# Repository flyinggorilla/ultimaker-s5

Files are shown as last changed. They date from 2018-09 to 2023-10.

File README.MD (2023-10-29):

# Ultimaker S3/S5/S5/S7/ProBundle Material Profiles

## favorite materials
* FormFutura ApolloX (all colors)
* FormFutura BVOH

## additional great materials
* FormFutura PythonFlex
* FormFutura CrystalFlex
* FormFutura HDglass PETG
* Luvocom PAHT 9933BK 

## materials i stopped using
* FormFutura Helios PVA (I switched all soluble support to BVOH, which is much more reliable and no clogging any more.)

## __FormFutura ApolloX ASA__ for outdoor parts
There is a FormFutura ApolloX listed on the marketplace, but that one is STILL not  supporting material station properly, because it misses color and additional material profile settings. So choose this one and you should be fine.

ApolloX prints as easy as PLA, but is much more robust and perfectly suited for practical parts and outdoor use as it is water resistant, UV resistant and doesnt bend under the heat of the sun. The really only tradeoff is weaker interlayer adhesion.

* ASA Materials are updated and tested with Ultimaker S3/S5 Firmware 8.2.x+ and Cura 5.5.x+
* The marketplace delivered ApolloX profiles are still as of v2.0.0 only providing the bare minimum, and have not been tuned for colors, material station, robustness, dimensional stability and more.
These profiles here are tuned for practical-use parts, with higher temperature for higher layer adhesion, and dimensional correctness also for larger prints. It is still super easy to print with Dimafix (or similar) in place.

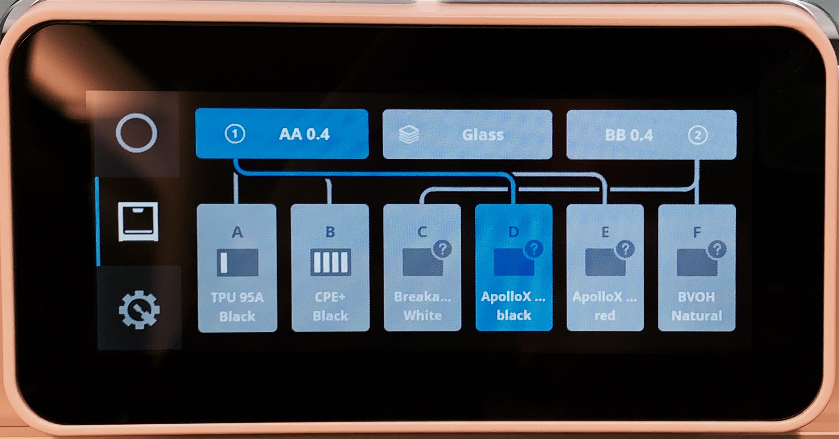
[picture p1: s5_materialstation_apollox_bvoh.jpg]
Formfutura ApolloX ASA and BVOH water soluble material


## __FormFutura BVOH__ water soluble support material
Forget PVA, BVOH is so much better more than justifying the higher price. Prints easier, didnt clog so far my BB 0.4, dissolves much quicker than PVA in warm water. Can be combined with many filaments, including ASA - my favorite material. Had so much of clogging issues with original Ultimaker PVA that i stopped using PVA entirely. Had then issues with FormFutura Helios PVA too.

## __Luvocom PAHT 9933BK__ for robust parts, but NOT outdoors. 
The biggest benefits of this Nylon material is much stronger inter-layer adhesion than ApolloX. Also it does not warp compared to other nylons. Prints well on Dimafix. Also it is fairly heat resistant.

This material is also available on the marketplace, but not optimized enough. Especially printing with 0.8mm Nozzle for larger parts caused lots of stringing. The profile lowered print temperature and increased retraction to reduce stringing. Drying the material upfront (12h 70°, or 4h 100°) is mandatory.

I learned the hard way, that this material strongly deforms in outdoor use, rendering it unusable.
ApolloX is still my favorite outdoor use material. However, I plan to test Durabio next, which is a PC/PMMA material that is UV resistant.

# Formfutura cardboard spool adapter for Ultimaker S5 and S3
FormFutura switched from plastic to cardboard spools recently. Great for environment, but problematic with Ultimaker spool holder, as the spools get stuck. This cardboard spool adapter for Ultimaker S3 and S5 will make it work again and uses little plastic. Printing two of these adapters solves the problem.

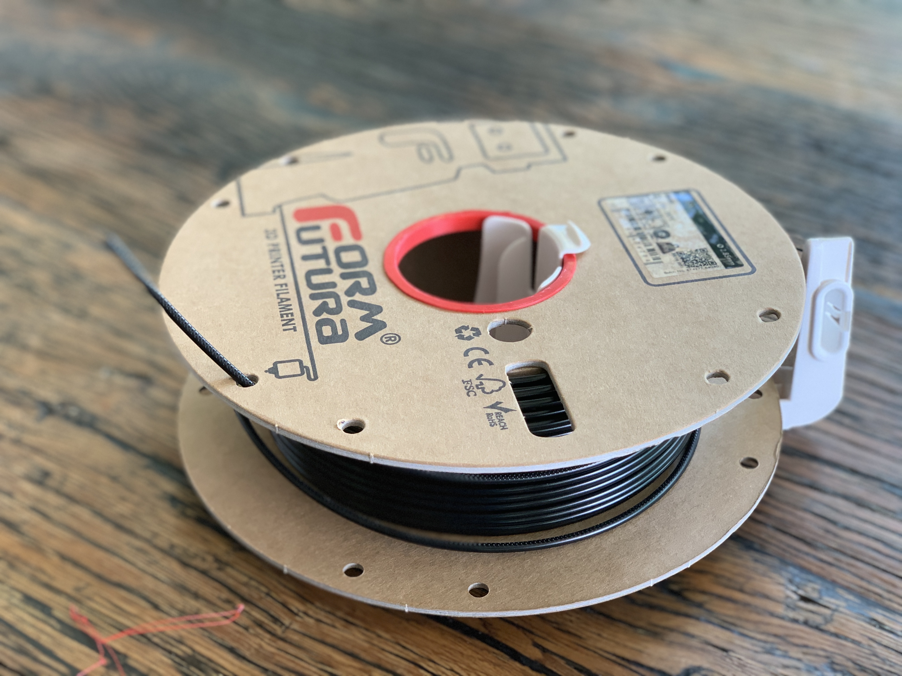
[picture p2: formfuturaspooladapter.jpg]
FormFutura cardboard spool adapter


https://grabcad.com/library/formfutura-cardboard-spool-adapter-for-ultimaker-s3-and-s5-1

# Python tool to manage material profiles on Ultimaker S3/S5/S5/S7/ProBundle printers
This tool allows to manage material profiles on Ultimaker S3/S5/S5/S7/ProBundle printers. It can be used to import, export, delete and list material profiles. 

## Material-Station
as of Cura 4.5 and S5 Firmware 5.5.12.20200226 there is no color information displayed with materials. this is ok for NFC based ultimaker material with color auto-detection, but not when manually assigning a 3rd party material to a material station bay.
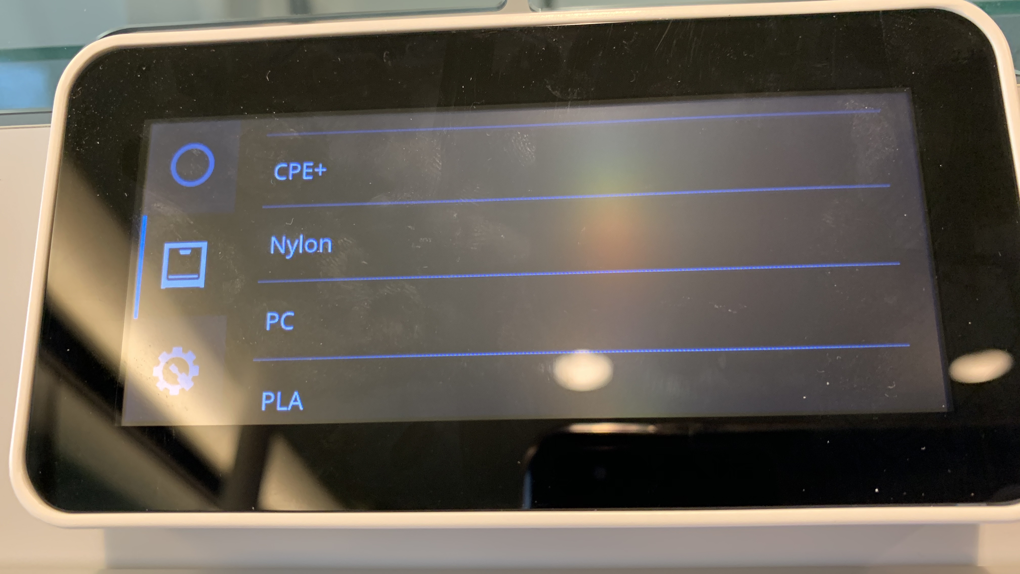
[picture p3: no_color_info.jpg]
no color information


The workaround for now is to turn every color variant into a unique material. This is what i did here for e.g. with ApolloX material.
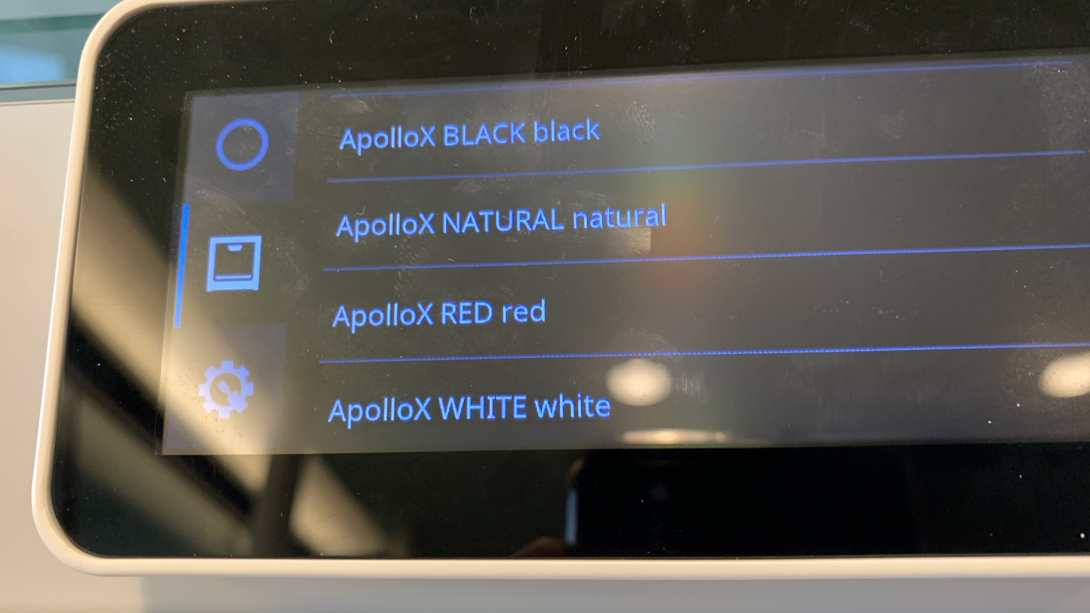
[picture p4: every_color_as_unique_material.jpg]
unique material per color variant


This is not nice as color info is now shown duplicate, but however, when importing those material profiles into cura, it all works fine.

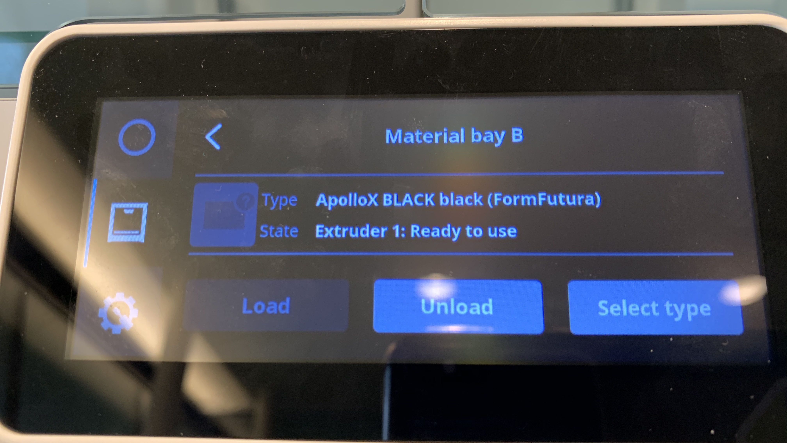
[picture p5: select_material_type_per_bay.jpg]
assign material type to bay


and finally it looks then like this when you have the material station. A mix of Ultimaker and FormFutura materials installed.

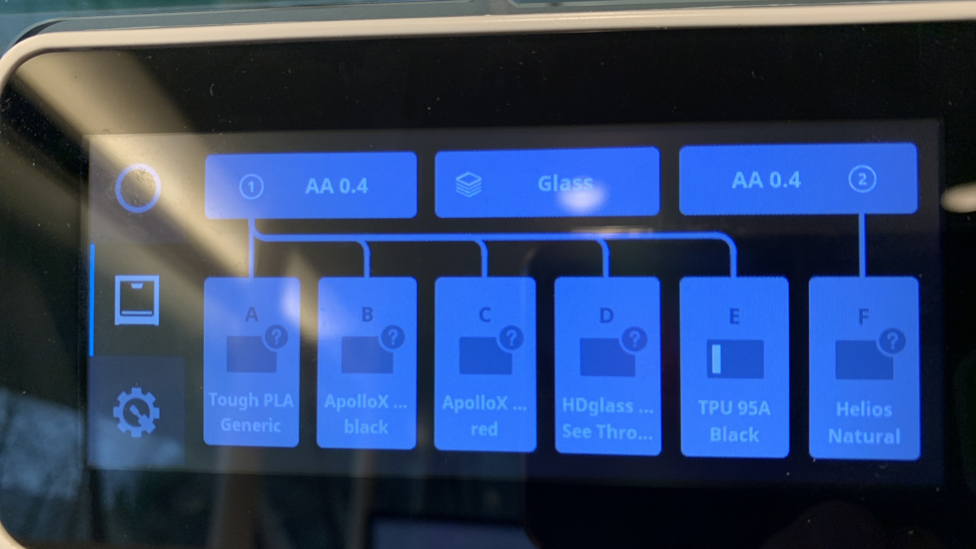
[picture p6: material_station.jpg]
material station


## Custom Material Upload Tool

__NOTE: you can import these profiles into Cura and Cura will send the materials to Ultimaker S5 on the next restart of Cura.__ this way you do not need to use the python script to upload the profiles into the printer. But for listing installed materials and for deleting material profiles from the printer this tool is very handy.

Uploading filament profiles via REST API to printer to add custom print profiles. e.g. I wanted that ASA (FormFutura ApolloX) and high-temperature PVA (FormFuture Helios) is selectable in the touch display.

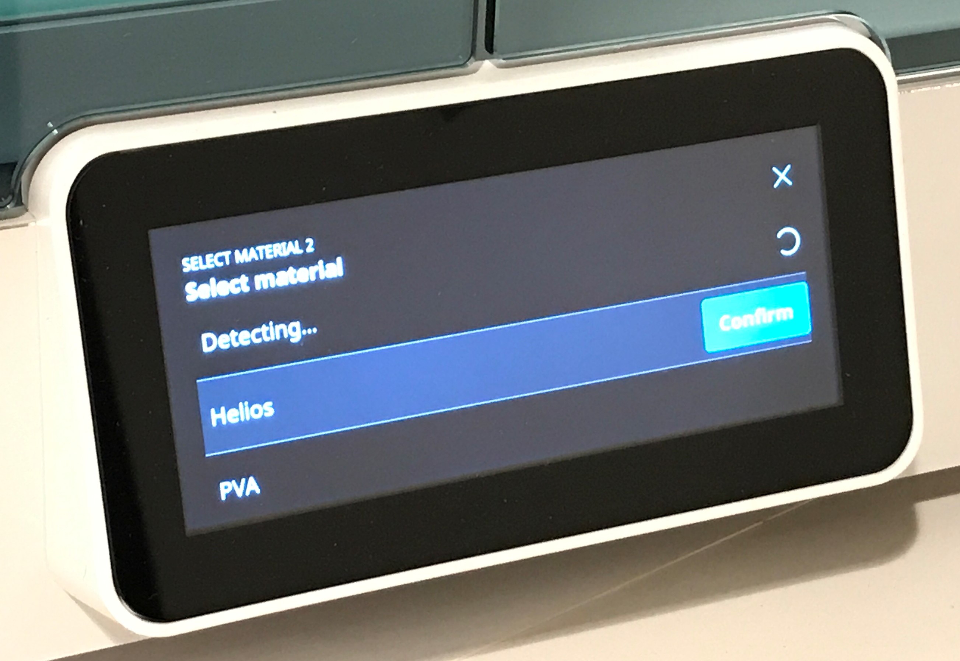
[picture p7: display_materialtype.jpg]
display materialtype


Therefore use the python tool (tested with Python 3.7+) ums5material.py

## Installing ums5material.py

### clone or copy from github

```
git clone https://github.com/flyinggorilla/ultimaker-s5.git
```

### install dependencies
```
python -m pip install requests
python -m pip install untangle
python -m pip install pyyaml
```

## Usage

### Help
```
python ums5material.py
```

note: on Linux you might need to use python3 instead.

```
Usage: ums5material.py [options] [ultimaker-url] [material-filename]

Options:
  -h, --help            show this help message and exit
  -f FILE, --file=FILE  Ultimaker S5 material XML file
  -u, --update          udpate to printer
  -l, --list            List materials on Ultimaker S5, provide optional
                        --filter string
  -F FILTER, --filter=FILTER
                        Filters listed materials filter string
  -g <guid>, --guid=<guid>
                        GUID of material
  -a <id>:<key>, --auth=<id>:<key>
                        digest authentication
  -s, --storeconfig     store given host and authentication information to
                        config file.
  -C, --createauth      create ID:KEY authentication credentials
                        writing/deleting materials. Please make sure to accept
                        authorization request on Ultimaker S5 printer display.
  -v, --verifyauth      Verify whether authentication against Ultimaker S5
                        REST api succeeds with provided ID/KEY.
  -d, --delete          delete material from printer with -g GUID or guid is
                        extracted from material xml file
```

## querying installed materials

option -l allows to list all installed materials. Option -s allows to store the hostname of Ultimaker S5 in the ums5material.config.yaml file so you dont have to retype it.

```
python ums5material.py -l -s http://ultimaker.local
```

an optional filter can be used with -F. in this example I query for installed FormFutura materials. Note that the Ultimaker S5 hostname/url is already automatically retrieved from the .config.yaml file.

```
python ums5material.py -l -F FormFutura 
```

results in this example output...
```
Material: FormFutura, Helios, Helios PVA, Natural, 5905b419-3c22-4530-aa64-eb8153b16e6e
Material: FormFutura, PythonFlex, PythonFlex TPU, Clear, 1ef7aea6-5634-4fc3-8d60-a04fcafe9ed5
Material: FormFutura, PETG, HDglass,  , ff6aaf9e-3fb0-420a-bd05-7a652eefeb80
Material: FormFutura, PythonFlex TPU, , Generic, 57d328ec-9b30-4c88-9158-7004035cd9d6
Material: FormFutura, ApolloX, ApolloX ASA, , e2383de0-2913-4777-b0f3-a03767d96529
Material: FormFutura, ASA, ApolloX, black, c99377f5-fbb4-4c3b-8f91-7a1d2c32e44f
Material: FormFutura, CrystalFlex, CrystalFlex SBC, Clear, a740135c-f874-4a14-99eb-15a04353d268
Material: FormFutura, Atlas, Atlas PVA, Natural, dd96bf72-866b-4770-b23e-e800e10e8cfa
```

## Modifying on-printer materials

### Create authorization token
modifying on-printer materials requires to have a token with proper permissions granted. you can use `ums5material.py` to create such a id/key token. You need to do this only once.

The option `-s` will store the ID/KEY credentials automatically in `ums5material.config.yaml` file so you dont need to type it for later use:

```
python ums5material.py -C -s
Keys generated: ID:KEY=8e54c3d79f35746547f06b9fd416d352:fa88da37b100807a7269d84a97381e4e6a8791191756f79dc28aa67c3bc7a382 200 {"id": "8e54c3d79f35746547f06b9fd416d352", "key": "fa88da37b100807a7269d84a97381e4e6a8791191756f79dc28aa67c3bc7a382"}
Please accept request on Ultimaker S5 display for application "ums5material.py" and user "flyinggorilla" to use keys.
```

### Upload material 
Now you have write access to upload and delete materials. 
But before you do this, ensure that your `.xml.fdm_material` file has a unique GUID, so especially when you manually copy an fdm_material you need to change the GUID. you can create GUIDs online on several sites, like the one here: https://www.guidgenerator.com

so your .xml.fdm_material should be updated like this...
```xml
<?xml version='1.0' encoding='utf-8'?>
<fdmmaterial version="1.3" 
  xmlns="http://www.ultimaker.com/material">
  <metadata>
    <name>
      <brand>FormFutura</brand>
      <material>PythonFlex</material>
      <color> </color>
      <!-- <label>Black PythonFlex TPU</label> -->
    </name>
    <GUID>57d328ec-9b30-4c88-9158-7004035cd9d6</GUID>
    <!-- <color_code>#000000</color_code> -->
    <compatible>True</compatible>
    <definition>fdmprinter</definition>
    <version>9</version>

...
...

```

so the following command will upload the new material. Note that the material will be overridden if it existed before

```
python ums5material.py -u FormFutura_PythonFlex_Generic.xml.fdm_material

Material filename: FormFutura_PythonFlex_Generic.xml.fdm_material
Contacting Ultimaker S5 at ultimaker.local with ID 082fba70255a02de03eb431c2dce774c
Material found: FormFutura PythonFlex PythonFlex TPU Generic 57d328ec-9b30-4c88-9158-7004035cd9d6
Deleted FormFutura_PythonFlex_Generic.xml.fdm_material: 200 {"message": "Remove successful", "result": true}
Posted FormFutura_PythonFlex_Generic.xml.fdm_material: 200 {"message": "Material profile stored", "result": true}
```

Note that the .dfm_material definitions with color information are good for Cura import. For the Ultimaker S5 printer display you should generate a Generic profile that has a single space character as `<color> </color>` definition. So you dont need to send the color versions to the printer.

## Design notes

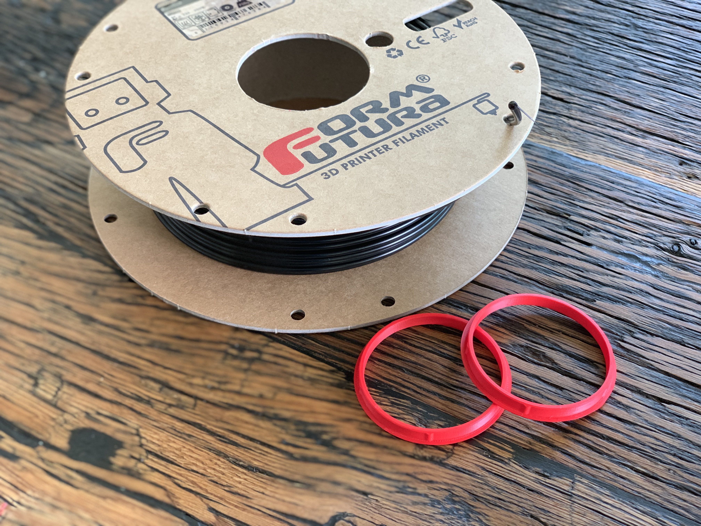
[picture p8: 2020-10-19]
formfutura spool adapter/20200627_124656008_iOS.jpg

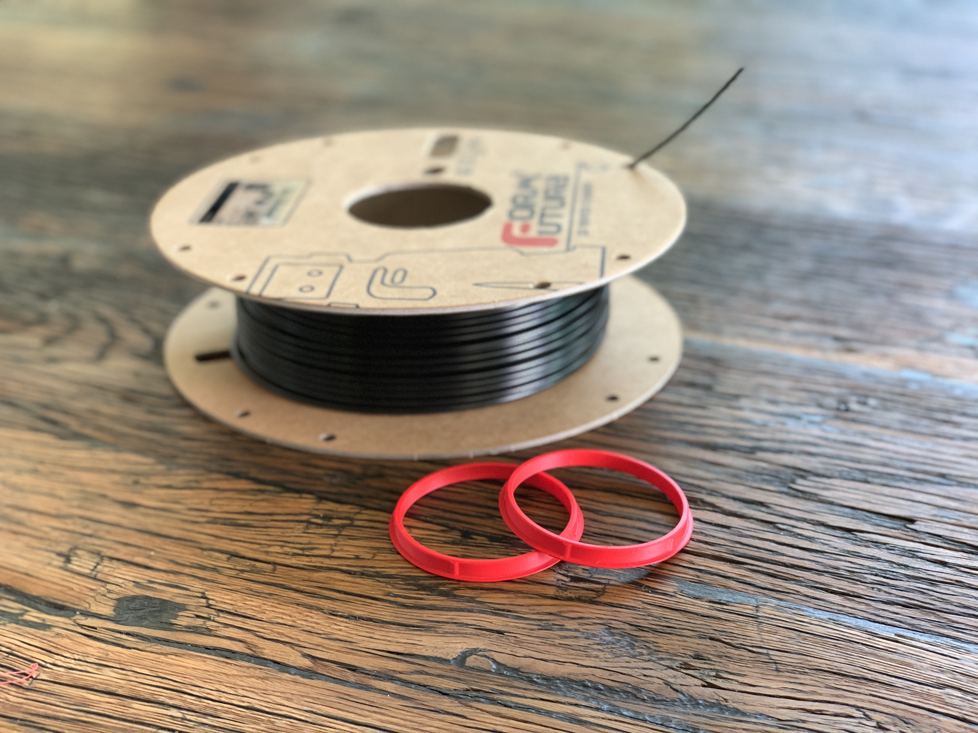
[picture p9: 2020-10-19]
formfutura spool adapter/20200627_124643468_iOS.jpg

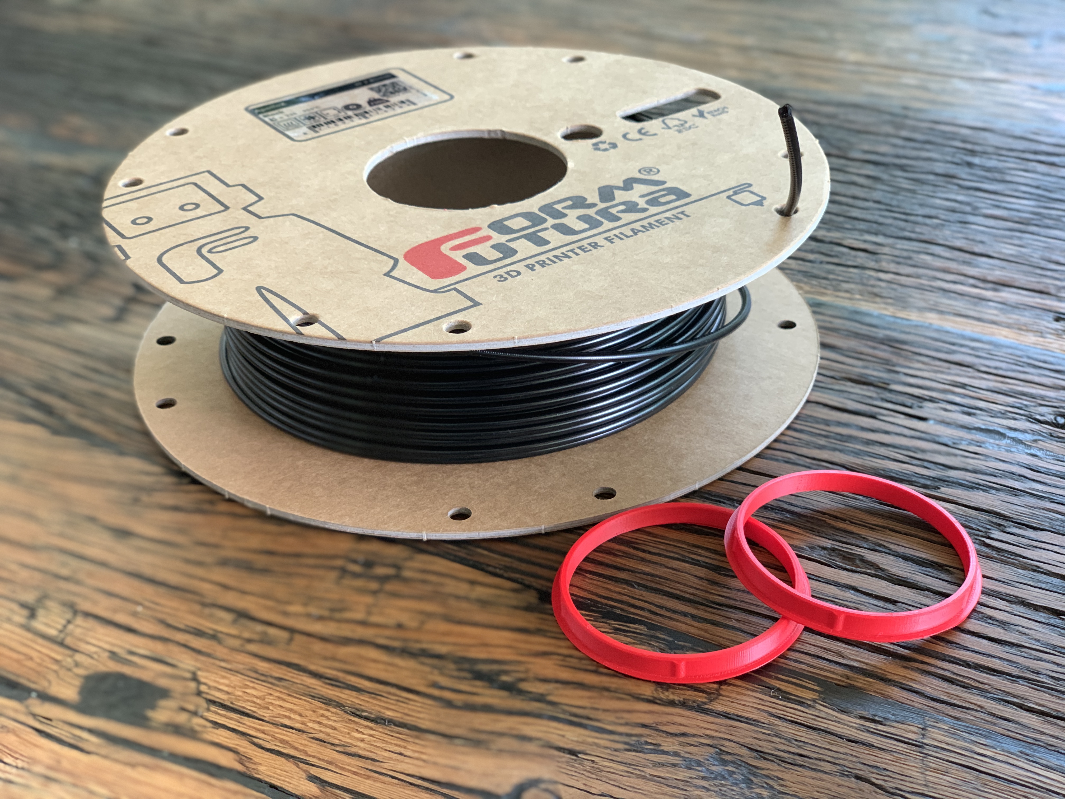
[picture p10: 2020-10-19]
formfutura spool adapter/20200627_124701642_iOS.jpg

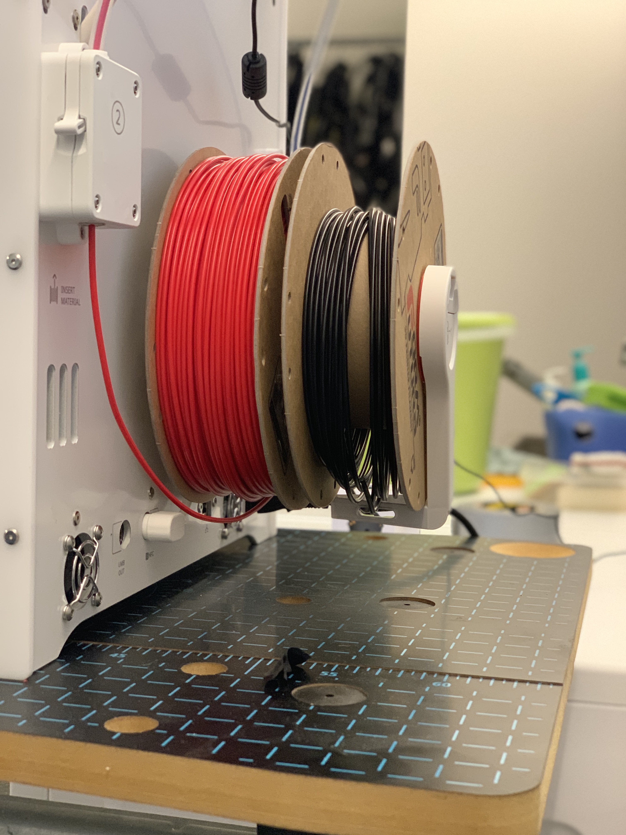
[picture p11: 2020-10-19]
formfutura spool adapter/20200628_083239896_iOS.jpg

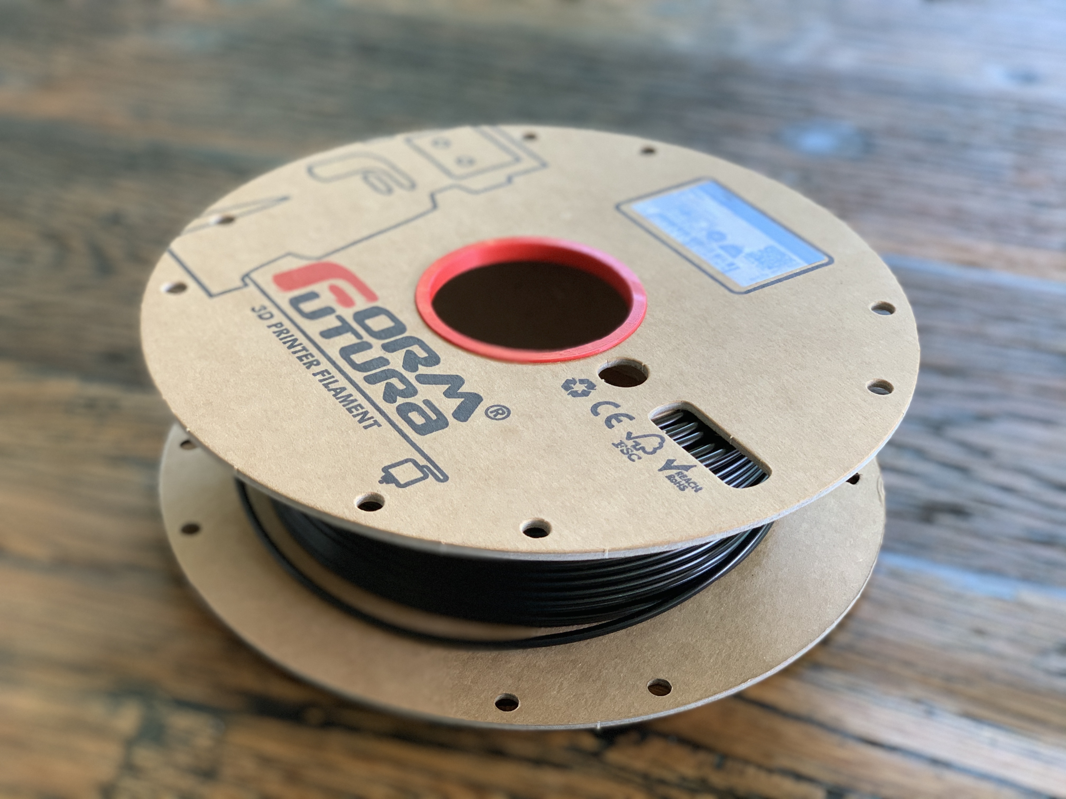
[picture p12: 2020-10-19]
formfutura spool adapter/20200627_124732581_iOS.jpg

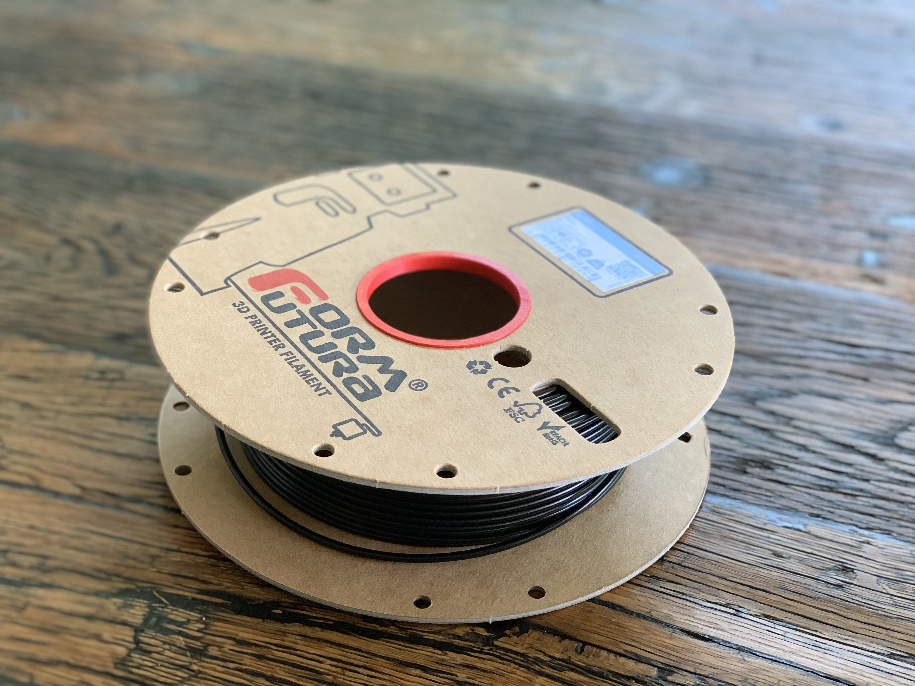
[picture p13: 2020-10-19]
formfutura spool adapter/20200627_124736101_iOS.jpg

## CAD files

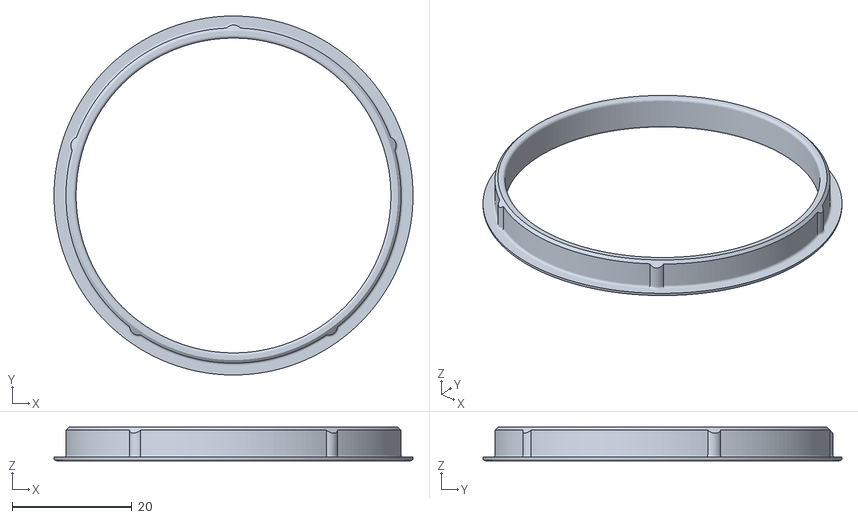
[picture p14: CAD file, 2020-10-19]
FormFutura Duo-Paperspool Adapter.stl
60.0 x 60.0 x 5.60

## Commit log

2018-09-04 fixed display of filament without color
2018-12-04 python tool for materials
2018-12-04 added filaments
2018-12-07 updates printing PythonFlex
2018-12-08 updated flex materials
2018-12-09 still tuning the material...
2019-11-16 support for materialstation
2020-02-23 updated materials to work with materialstation
2020-02-23 updated documentation for material station
2020-02-23 fixed additional materials for material-station
2020-03-22 updated material change information
2020-10-19 added bvoh and spool adapter
    [FormFutura Duo-Paperspool Adapter.stl]
2020-10-20 adding filament info
2020-10-22 commented build temperature
2020-12-08 wrong print core definition for S3
2020-12-08 fixed print core definition for S3
2021-04-06 updates to materials
2021-11-30 updated colorfab tpu initial layer flow
2022-09-06 optimized BVOH print and retract speeds to avoid frequent clogging
2022-09-11 adding optimized luvocom filament
2023-10-26 fix missing break temperature causes ERR999
2023-10-29 updated colors of materials. updated apollox ASA and HDglass
2023-11-01 adding custom tuned Durabio material profile
2023-12-16 adding new materials
2025-02-13 adding Arnitel Addigy flexible Shore 34D filament
2025-03-02 updated arnitel addigy 2045 for slower printing and better results
